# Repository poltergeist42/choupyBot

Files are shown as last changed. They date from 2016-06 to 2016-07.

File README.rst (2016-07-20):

=========
choupyBot
=========

   :Autheur:          `Poltergeist42 <https://github.com/poltergeist42>`_
   :Organistation:    `VoLAB <https://github.com/volab>`_
   :Projet:           `choupyBot <https://github.com/volab/choupyBot>`_
   :Licence:          CC BY-NC-SA 4.0
   :Liens:            https://creativecommons.org/licenses/by-nc-sa/4.0/ 

------------------------------------------------------------------------------------------

Description
===========

ChoupyBot est un petit "robot" animé par un Raspberry pi et motoriser par 2 moteurs
pas à pas (PAP) et un capteur ultrason.

L'objectif de ce projet et de réaliser une petite plateforme ludique qui pourra être
programmée / commandée à distance par un enfant. Ce robot évoluera dans un quadrillage
de 15x15.

**N.B :** la dimension des cases sera déterminée ultérieurement en fonction
de la taille du robot.

Voir le doc de conception pour plus de détail :
https://github.com/volab/choupyBot/blob/master/_1_userDoc/choupyBot_doc.rst

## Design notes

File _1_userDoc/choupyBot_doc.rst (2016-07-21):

=========
choupyBot
=========

   :Autheur:                    `Poltergeist42 <https://github.com/poltergeist42>`_
   :Organistation:              `VoLAB <https://github.com/volab>`_
   :Projet:                     `choupyBot <https://github.com/volab/choupyBot>`_
   :Licence:                    CC BY-NC-SA 4.0
   :Liens:                      https://creativecommons.org/licenses/by-nc-sa/4.0/ 

------------------------------------------------------------------------------------------

    :Version:                   20160721

------------------------------------------------------------------------------------------

Outils de conception
=======================

    :Langage de programmation:  Python (v3.4)
    :modelisation 3D:           Fusion 360
    :Circuit imprime:           Kicad (v4.0.2)

------------------------------------------------------------------------------------------

Description
===========

ChoupyBot est un petit "robot" animé par un Raspberry pi et motoriser par 2 moteurs
pas à pas (PAP) et un capteur ultrason.

L'objectif de ce projet et de réaliser une petite plateforme ludique qui pourra être
programmée / commandée à distance par un enfant. Ce robot évoluera dans un quadrillage
de 15x15.

**N.B :** la dimension des cases sera déterminée ultérieurement en fonction
de la taille du robot.

------------------------------------------------------------------------------------------

Descriptif détaillé
===================

    #. Liste des équipements
        * Un capteur ultrason
            Il vat permettre la détection des obstacles. Un potentiomètre sera associé
            à ce capteur pour permettre de modifier la distance de sécurité avant
            Évitement des obstacles.
            
            **N.B :** Le RPi n'étant pas équiper d'une entrée analogique et ne voulant
            ajouter un CAN, le potentiomètre ne sera pas intégré pour l'instant.
            
        * Un bouton "Start"
            Lorsque la programmation du robot par l'utilisateur sera terminé,
            le robot attendra que le bouton "Start" soit enfoncé avant de commencer.
            Des LED peuvent être placés à coté pour indiquer si on est en mode Action
            ou Programmation
            
            **N.B** : Si le bouton n'est pas physique mais fait partie de l'interface,
            il ne sera pas nécessaire d'ajouter les LED.
            
    #. Les modes disponibles sont
    
        * **Boxxle** : Le robot doit manipuler une boite sur un damier a fin de la
          ranger sur un emplacement défini en évitant les obstacles. Les
          Instructions seront données par un opérateur depuis un terminal externe.
          
        * **Parcours** : Le robot doit suivre un parcours (ou un labyrinthe).
          Lorsque le robot aura suivi le parcours ou résolue le labyrinthe, le
          robot pourra refaire le trajet de façon optimisé.
          
        * **Aventure** : le robot évolue librement au sol et réagi en fonction des
          obstacles qu'il rencontre.
          
          **N.B** : Le Robot n'ayant qu'un seul capteur, ce dernier ne réagira
          pas beaucoup.
            
    #. Besoin et fonctionnalités pour la "programmation" coté publique
        * Création d'un programme et d'un interface pour tablettes Android et / ou PC
            - 4 boutons de base : Avance, Recul, Gauche, Droite
            - 1 menu déroulant permettant de choisir le mode disponible : Boxxle, Parcours,
              Aventure.
            - 1 paire de bouton radio Start / Stop
            
        * Arrêt du système
            - L'interface doit contenir un onglet ; une page ; ou un bouton permettant
              d'éteindre le RPi. Une foie le système arréter, un message doit nous
              informer que l'appareil peut être mis hors tension.

------------------------------------------------------------------------------------------

Références matériels
====================

    :reference du moteur Pas a Pas:         28BJY-48
    :reference du driver pour le PAP:       UNL2003
    :reference du capteur ultrason:         HC-SR04
    :reference du Raspberry Pi:             Raspberry Pi2
    :reference Battery:                     Lipo Battery 7.4V
    :reference abaisseur de tension:        UBEC 5v 3a
    :reference electronique:
        +------------------------------------------------------------------------------+
        |                           Carte éléctronique                                 |
        +--------------------------+-----+---------------------------------------------+
        |          Référence       | QTE |                 Descriptif                  |
        +==========================+=====+=============================================+
        | Resistor 20K             |  1  | pond diviseur pour abesser la tension en    |
        +--------------------------+-----+ sortie de la broche 'echo' (+5v) jusqu'à la |
        | Resistor 10k             |  1  | tension d'entrée des GPIO du RPi            |
        +--------------------------+-----+---------------------------------------------+
        | Resistor 330R            |  1  | Control de reception, par 'echo', du son    |
        +--------------------------+-----+ émit par 'trig'. Cette ensemble est         |
        | Red LED 5mm              |  1  | facultatif                                  |
        +--------------------------+-----+---------------------------------------------+
        | Pin_Header_Straight_1x02 |  2  | P1, entrée Ubec. P10 N.U, en cas de besoin  |
        +--------------------------+-----+---------------------------------------------+
        | Pin_Header_Straight_1x03 |  1  | Broches I2c du Pi, en cas de besoin         |
        +--------------------------+-----+---------------------------------------------+
        | Pin_Header_Straight_2x20 |  1  | Pour relier le PCB au Pi                    |
        +--------------------------+-----+---------------------------------------------+
        | XH_connector_4pins_Vert  |  3  | Pour le sonar et les 2 drivers de PAP       |
        +--------------------------+-----+---------------------------------------------+
        | XH_connector_2pins_Vert  |  4  | Pour alimenter les diférents elements       |
        +--------------------------+-----+---------------------------------------------+
        | 40 Pin Flat grey Ribbon  |  1  | Nape permettant de relier le RPi à la carte |
        | Cable                    |     | du robot                                    |
        +--------------------------+-----+---------------------------------------------+
        | 40 Pin IDC FC Female     |     | Connecteur à placer sur chaque extremité    |
        | Header Cable Socket      |  2  | de la nape une fois coupée aux bonnes       |
        | Connector FC-40          |     | dimensions                                  |
        +--------------------------+-----+---------------------------------------------+
        
        +------------------------------------------------------------------------------+
        |                           Autres Composant                                   |
        +--------------------------+-----+---------------------------------------------+
        |          Référence       | QTE |                 Descriptif                  |
        +==========================+=====+=============================================+
        | Mini Digital Voltmeter   |  1  | Permet de mesurer la tension de la battery  |
        +--------------------------+-----+---------------------------------------------+
        | spdt toggle switch 2     |  1  | Switch Permettant la mise sous tension et   |
        | position                 |     | la mise hors tension                        |
        +--------------------------+-----+---------------------------------------------+
        
    :ref fournisseur:
        * `Resistor <http://www.aliexpress.com/item/1Pack-300Pcs-10-1M-Ohm-1-4w-Resistance-1-Metal-Film-Resistor-Resistance-Assortment-Kit-Set/32505894332.html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,searchweb201602_3_10057_10056_10055_10037_10049_10033_10059_10032_10058_10017_405_404_407_10040,searchweb201603_1&btsid=8e5d318c-a269-4c5b-a395-16bc8a31fc73>`_
        
        * `Red LED 5mm <http://www.aliexpress.com/item/Free-shipping-100pcs-Red-LED-5MM-Red-light-emitting-diode-Red-turn-Red/32628839823.html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,searchweb201602_3_10057_10056_10055_10037_10049_10033_10059_10032_10058_10017_405_404_407_10040,searchweb201603_1&btsid=47854a59-62f5-488d-87f2-74b3ebb1b718>`_

        * `Pin_Header_Straight(SIL) <http://www.aliexpress.com/item/20pcs-lot-Connector-2-54mm-40-Pin-Male-Single-Row-silver-Pin-Header-Strip-Free-Shipping/606254600.html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,searchweb201602_3_10057_10056_10055_10037_10049_10033_10059_10032_10058_10017_405_404_407_10040,searchweb201603_1&btsid=45858581-d831-43e6-adae-868ebc290c68>`_

        * `Pin_Header_Straight (DIL) <http://www.aliexpress.com/item/5PCS-LOT-2-54mm-2-x-40-Pin-Male-Double-Row-Pin-Header-Strip-pin-header/32639552444.html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,searchweb201602_3_10057_10056_10055_10037_10049_10033_10059_10032_10058_10017_405_404_407_10040,searchweb201603_1&btsid=45858581-d831-43e6-adae-868ebc290c68>`_

        * `XH_connector <http://www.aliexpress.com/item/40-sets-Kit-in-box-2p-3p-4p-5-pin-2-54mm-Pitch-Terminal-Housing-Pin/32682649292.html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>`_
 
        * `40 Pin Flat grey Ribbon Cable <http://www.aliexpress.com/item/1meter-free-shipping-40-Pin-1-27mm-Spacing-2-54mm-Pitch-Extension-Flat-grey-Ribbon-Cable/32695430026.html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>`_
        
        * `40 Pin IDC FC Female Header Cable Socket Connector FC-40 <http://www.aliexpress.com/item/50-Pcs-2-54mm-2x20-Pin-40-Pin-IDC-FC-Female-Header-Cable-Socket-Connector-FC/32425419419.html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,searchweb201602_3_10057_10056_10055_10037_10049_10033_10059_10032_10058_10017_405_404_407_10040,searchweb201603_1&btsid=aadd4877-4555-4aa3-bfb5-1c5a960b74ee>`_
        
        * `Step motor + Drivers <http://www.aliexpress.com/item/5V-4-Phase-Stepper-Step-Motor-Driver-Board-ULN2003-With-Drive-Test-Module-Machinery-Board-Tools/32532201168.html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,searchweb201602_3_10057_10056_10055_10037_10049_10033_10059_10032_10058_10017_405_404_407_10040,searchweb201603_1&btsid=5e1b0c4c-c554-49cf-8065-2a162d1b7fc5>`_
        
        * `HC-SR04 Ultrasonic <http://www.aliexpress.com/item/5pcs-HC-SR04-Ultrasonic-Module-Distance-Measuring-Transducer-Sensor-Detector-Ranging-Module-DC-5V/1787674353.html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,searchweb201602_3_10057_10056_10055_10037_10049_10033_10059_10032_10058_10017_405_404_407_10040,searchweb201603_1&btsid=fbf652a2-1388-4059-8230-f07c7a479e81>`_

        * `Raspberry Pi 3 (le 2 est épuisé) <http://www.rs-particuliers.com/WebCatalog/Raspberry_Pi_Model_3_B_SBC-8968660.aspx>`_
        
        * `Lipo Battery 7.4V <http://www.aliexpress.com/item/New-Lion-Power-Lipo-Battery-7-4V-2S-900Mah-25C-High-Power-For-RC-Helicopter-Quadcopter/32490119056.html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,searchweb201602_3_10057_10056_10055_10037_10049_10033_10059_10032_10058_10017_405_404_407_10040,searchweb201603_1&btsid=5df62305-c0ef-4954-b372-49875b600234>`_
        
        * `UBEC <http://www.aliexpress.com/item/DC-Converter-Module-3A-5V-Mini-UBEC-For-RC-Plane-Quadcopter-UBEC-For-FPV-Image-Transmission/32672871968.html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,searchweb201602_3_10057_10056_10055_10037_10049_10033_10059_10032_10058_10017_405_404_407_10040,searchweb201603_1&btsid=782431b5-bf7c-4989-af00-d58d274b1460>`_
        
        * `Mini Digital Voltmeter <http://www.banggood.com/0_28-Inch-2_5V-30V-Mini-Digital-Voltmeter-p-974258.html>`_
        
        * `spdt toggle switch <http://www.aliexpress.com/item/2-Pcs-AC-125V-6A-Amps-ON-ON-2-Position-3-Pins-SPDT-Mini-Toggle-Switch/32616445190.html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,searchweb201602_3_10057_10056_10055_10037_10049_10033_10059_10032_10058_10017_405_404_407_10040,searchweb201603_1&btsid=3ba9a450-a00f-4e04-ab23-c6719cd05a1d>`_

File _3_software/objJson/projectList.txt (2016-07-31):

C:/mntJeanCloud/Perso/LAB/Pierre/raspberryPi/projet/choupyBot/_3_software

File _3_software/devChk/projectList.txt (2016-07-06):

C:/mntJeanCloud/Perso/LAB/Pierre/raspberryPi/projet/scanner3d/_3_software
C:/mntJeanCloud/Perso/LAB/Pierre/raspberryPi/projet/choupyBot/_3_software

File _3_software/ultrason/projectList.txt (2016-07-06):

C:/mntJeanCloud/Perso/LAB/Pierre/raspberryPi/projet/choupyBot/_3_software

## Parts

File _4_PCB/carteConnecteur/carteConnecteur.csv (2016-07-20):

Id | Référence | Boîtier | Quantité | Désignation | Fournisseur et réf.
1 | D1 | LED-5MM | 1 | LED
2 | P6 | Pin_Header_Straight_2x20 | 1 | RPi_Conn
3 | P10 | Pin_Header_Straight_1x02 | 1 | N.U
4 | R1 | Resistor_Vertical_RM5mm | 1 | 20k
5 | R2 | Resistor_Vertical_RM5mm | 1 | 10k
6 | R3 | Resistor_Vertical_RM5mm | 1 | 330R
7 | P11 | Pin_Header_Straight_1x03 | 1 | I2c
8 | REF**,REF** | MountingHole_3.7mm_Pad | 2 | MountingHole_3.7mm_Pad
9 | P1 | Pin_Header_Straight_1x02 | 1 | +5 (ubec)
10 | P2 | XH_connector_4pins_Vert | 1 | PAP_D
11 | P3 | XH_connector_2pins_Vert | 1 | +5 (pap_G)
12 | P4 | XH_connector_2pins_Vert | 1 | +5 (pap_D)
13 | P5 | XH_connector_4pins_Vert | 1 | PAP_G
14 | P7 | XH_connector_2pins_Vert | 1 | +5 (sonar)
15 | P8 | XH_connector_2pins_Vert | 1 | +5 (RPi)
16 | P9 | XH_connector_4pins_Vert | 1 | HC-SR04

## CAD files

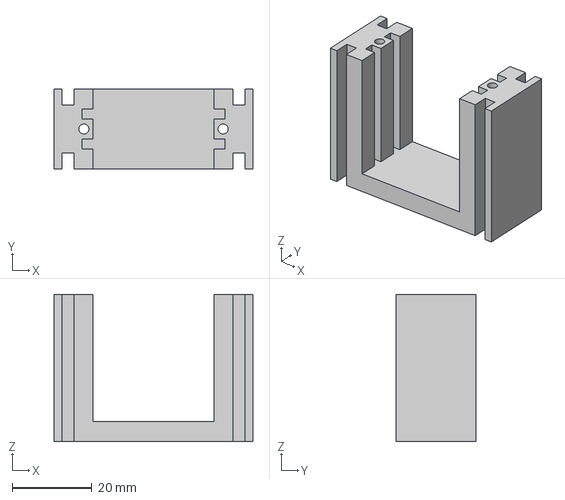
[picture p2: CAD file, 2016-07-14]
_2_modelization/fusion 360/supportElectronique v9.iges
50.0 x 20.0 x 37.0 mm

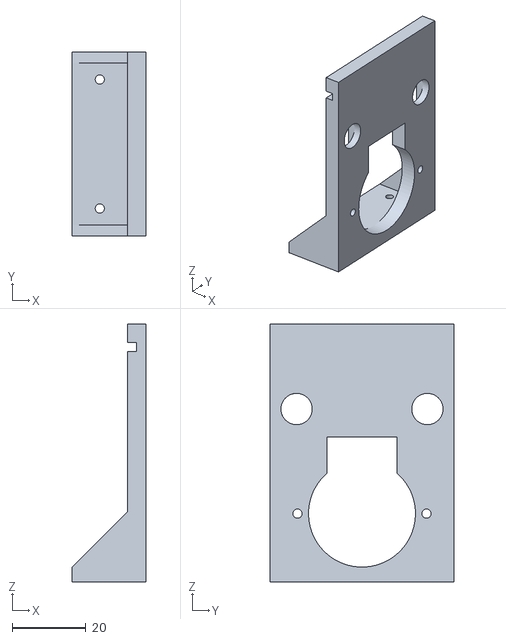
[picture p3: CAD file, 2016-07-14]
_2_modelization/stl/equerreMoteur.stl
20.0 x 50.0 x 70.0

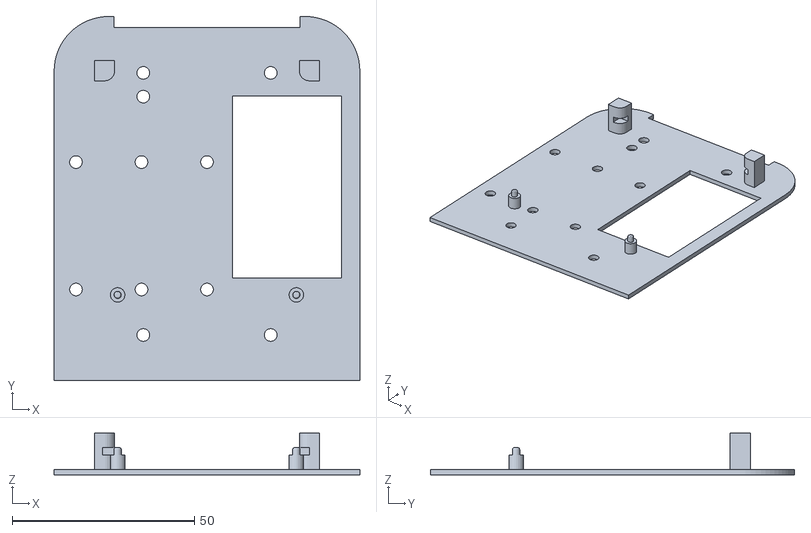
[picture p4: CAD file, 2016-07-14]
_2_modelization/stl/supportPi v16.stl
84.0 x 100.0 x 11.5

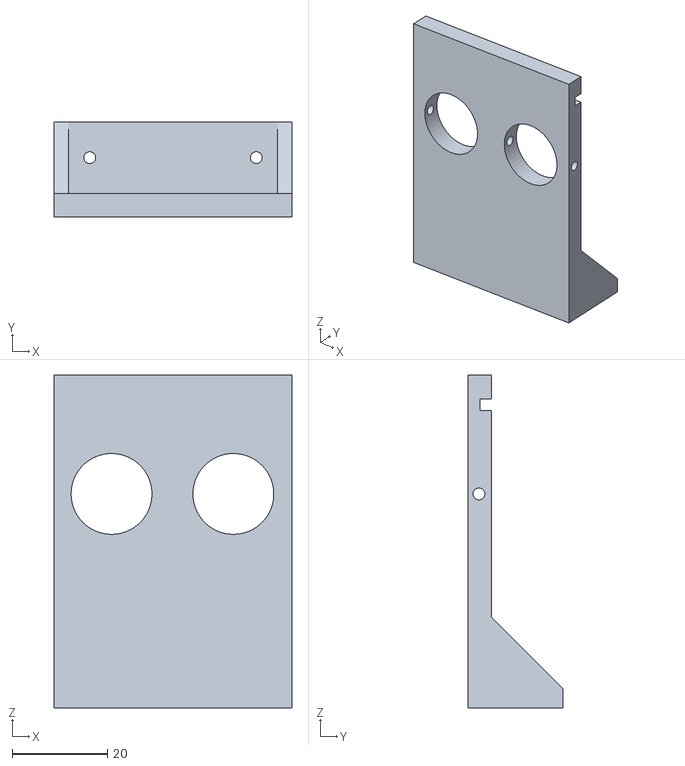
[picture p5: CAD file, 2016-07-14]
_2_modelization/stl/equerreSonar.stl
50.0 x 20.0 x 70.0

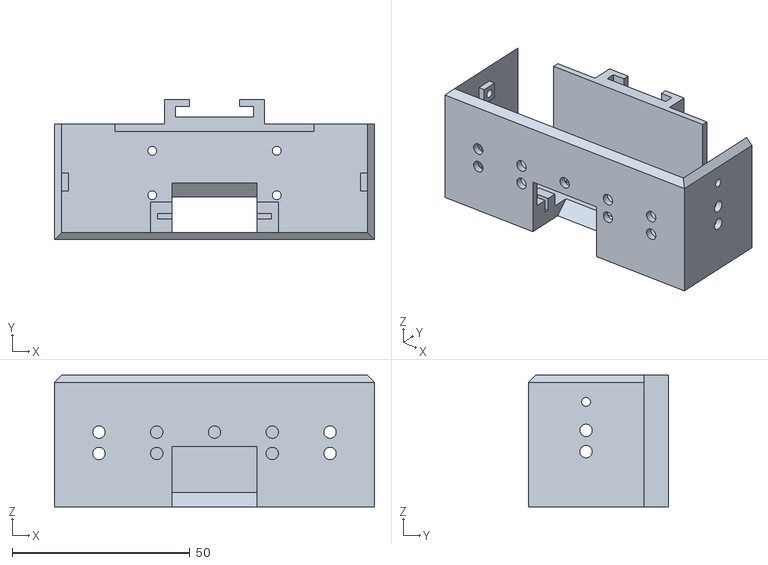
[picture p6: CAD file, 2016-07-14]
_2_modelization/stl/packBattery v23.stl
90.0 x 39.5 x 37.0

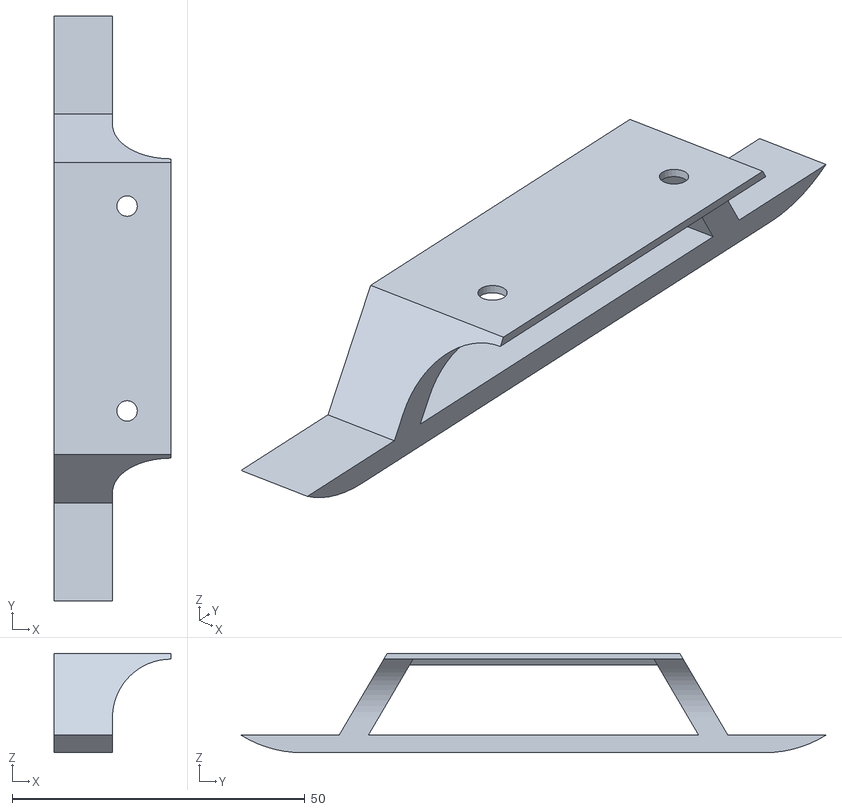
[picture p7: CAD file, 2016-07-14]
_2_modelization/stl/patin v8.stl
20.0 x 100.0 x 17.0

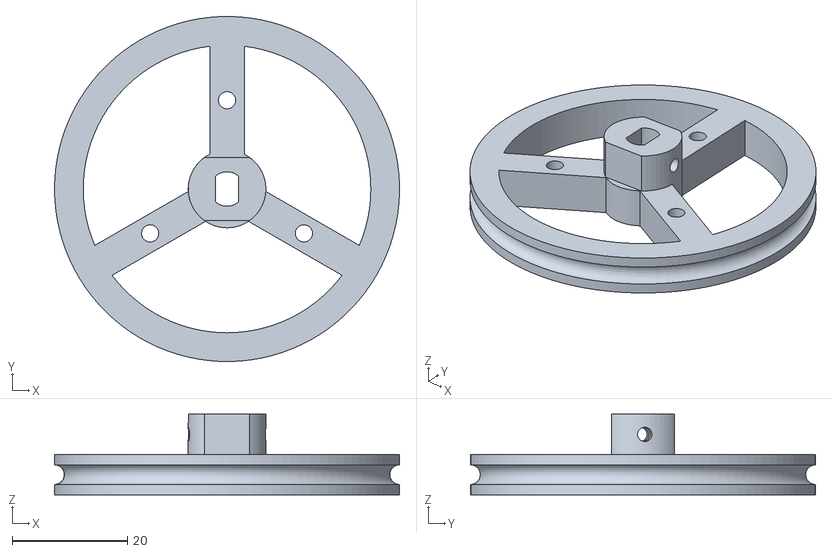
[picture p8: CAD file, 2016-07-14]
_2_modelization/stl/roue v8.stl
60.0 x 60.0 x 14.0

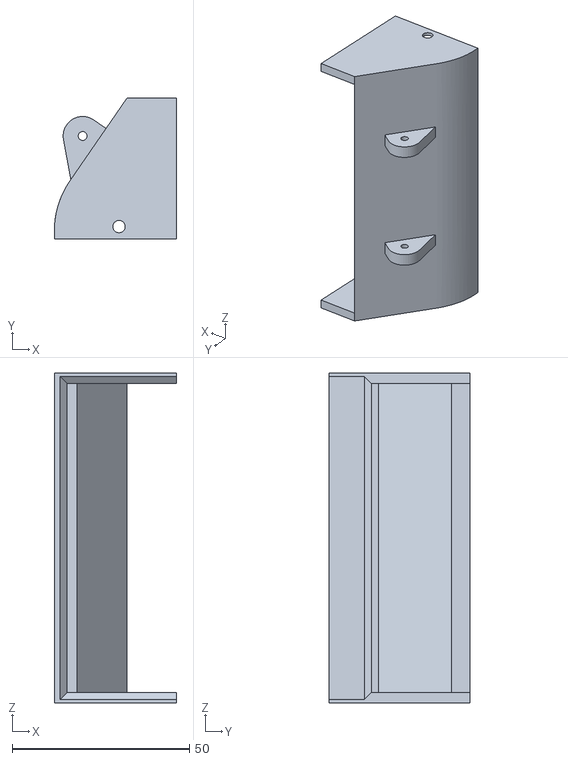
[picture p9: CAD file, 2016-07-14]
_2_modelization/stl/capotDeCoffre v16.stl
34.5 x 39.8 x 93.0

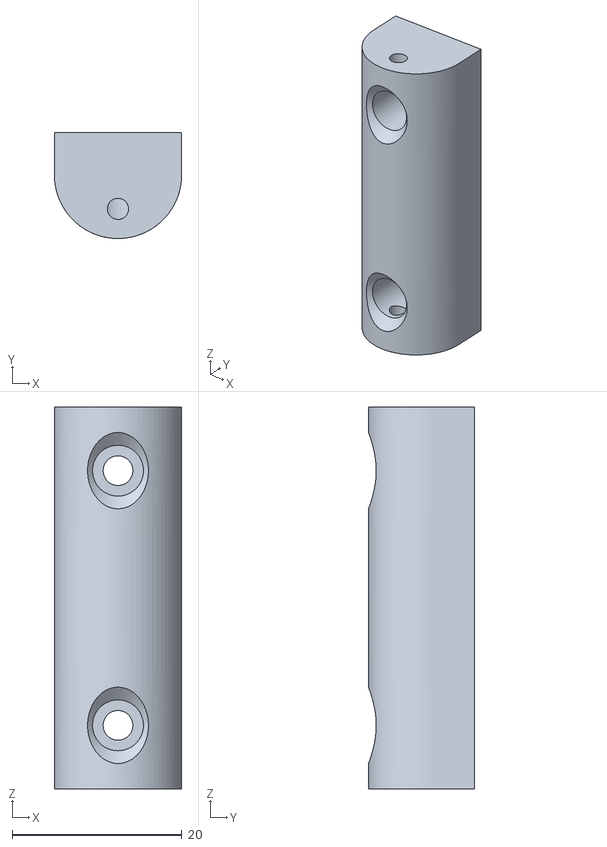
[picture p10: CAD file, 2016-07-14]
_2_modelization/stl/support.stl
15.0 x 12.5 x 45.0

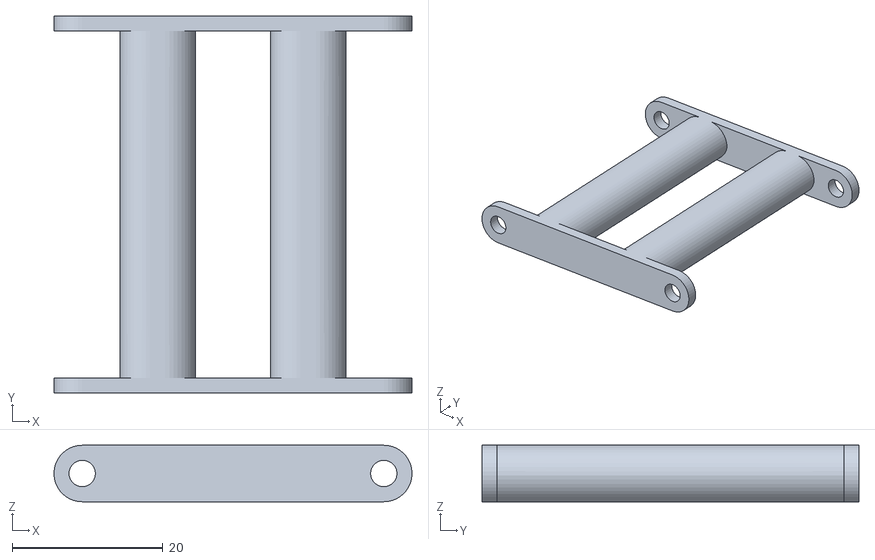
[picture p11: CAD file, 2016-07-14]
_2_modelization/stl/fixationCapotSpoiler v4.stl
47.5 x 50.0 x 7.50

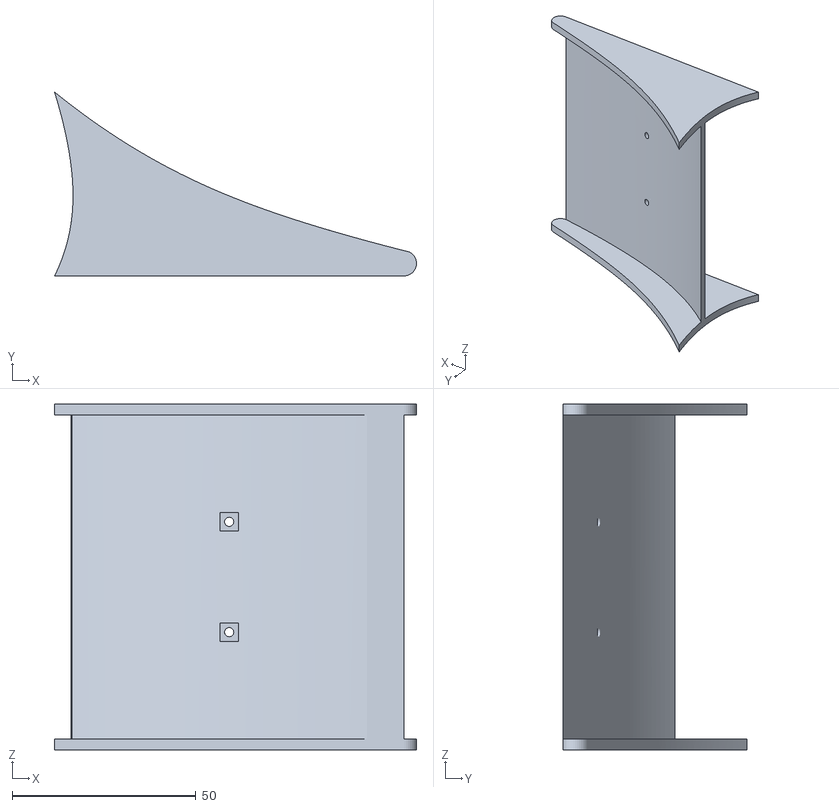
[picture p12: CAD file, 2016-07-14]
_2_modelization/stl/spoiler.stl
98.4 x 50.0 x 94.0

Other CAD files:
_2_modelization/stl/supportElectronique v9.stl
_2_modelization/fusion 360/capotDeCoffre v16.f3d
_2_modelization/fusion 360/equerreMoteur.f3d
_2_modelization/fusion 360/equerreSonar.f3d
_2_modelization/fusion 360/fixationCapotSpoiler v4.f3d
_2_modelization/fusion 360/packBattery v23.f3d
_2_modelization/fusion 360/patin v8.f3d
_2_modelization/fusion 360/roue v8.f3d
_2_modelization/fusion 360/spoiler v9.f3d
_2_modelization/fusion 360/supportPi v16.f3d

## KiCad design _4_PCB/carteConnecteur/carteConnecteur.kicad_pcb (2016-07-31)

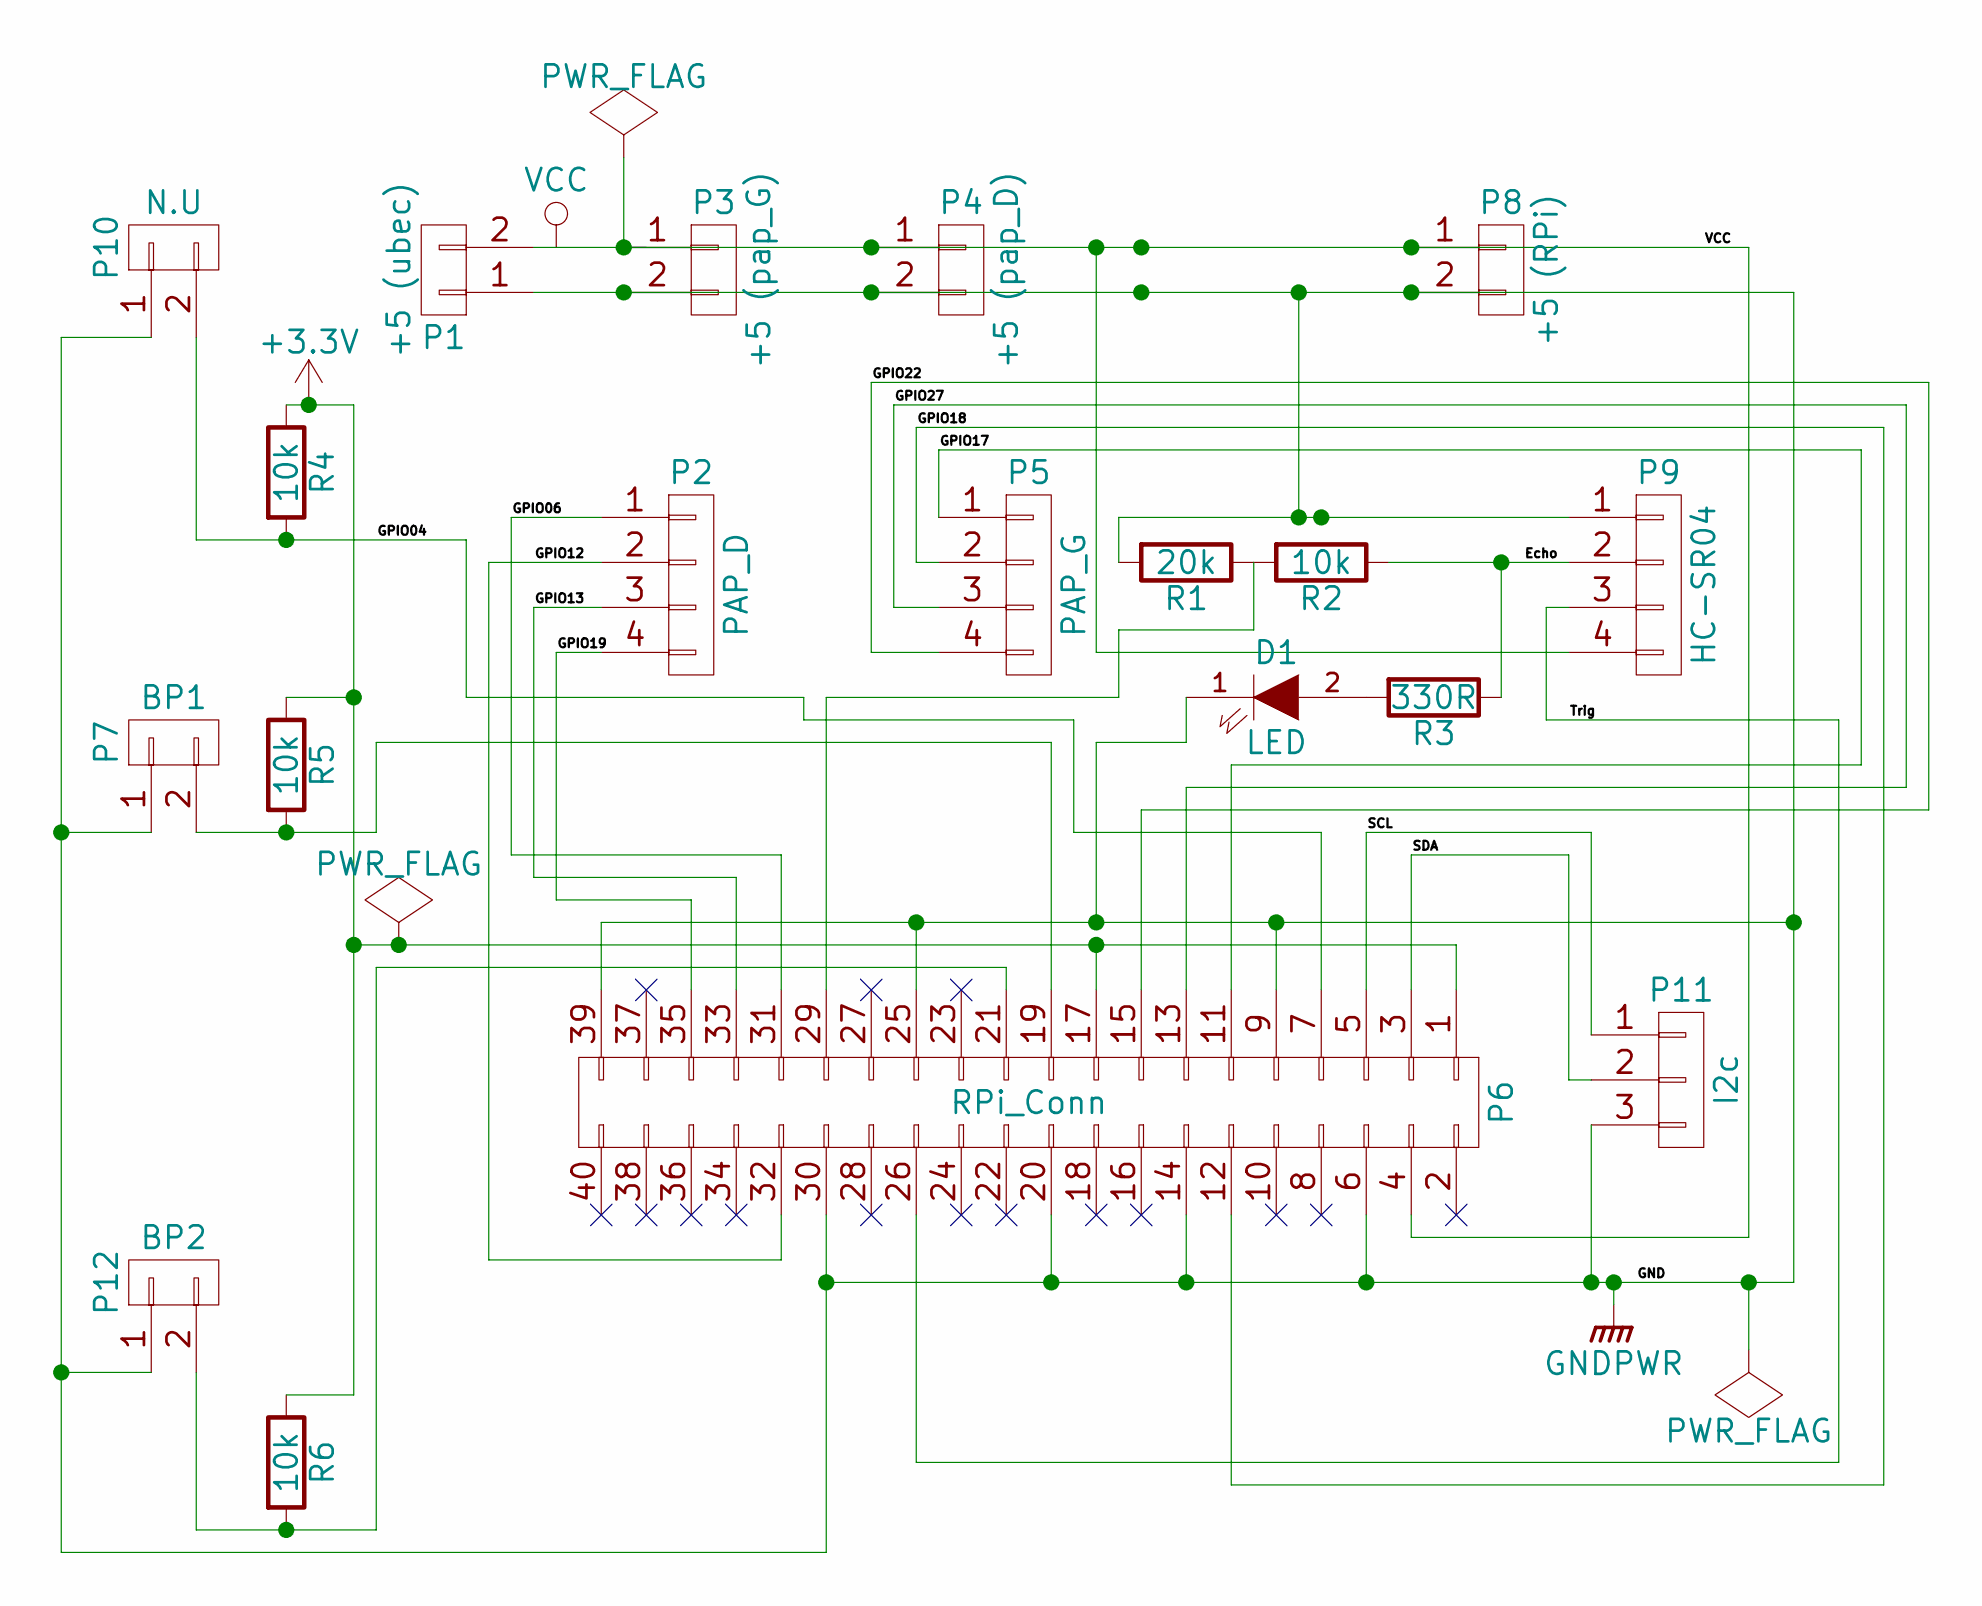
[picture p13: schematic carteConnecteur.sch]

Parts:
D1: LED; LED-5MM
P1: +5 (ubec); Pin_Header_Straight_1x02
P2: PAP_D; XH_connector_4pins_Vert
P3: +5 (pap_G); XH_connector_2pins_Vert
P4: +5 (pap_D); XH_connector_2pins_Vert
P5: PAP_G; XH_connector_4pins_Vert
P6: RPi_Conn; Pin_Header_Straight_2x20
P7: BP1; Pin_Header_Straight_1x02
P8: +5 (RPi); XH_connector_2pins_Vert
P9: HC-SR04; XH_connector_4pins_Vert
P10: N.U; Pin_Header_Straight_1x02
P11: I2c; Pin_Header_Straight_1x03
P12: BP2; Pin_Header_Straight_1x02
R1: 20k; Resistor_Vertical_2-54
R2, R4, R5, R6: 10k; Resistor_Vertical_2-54
R3: 330R; Resistor_Vertical_2-54

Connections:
+3V3: P6.1, P6.17, R4.1, R5.1, R6.1
/Echo: P9.2, R2.1, R3.1
/GPIO04: P6.7, P10.2, R4.2
/GPIO06: P2.1, P6.31
/GPIO12: P2.2, P6.32
/GPIO13: P2.3, P6.33
/GPIO17: P5.1, P6.11
/GPIO18: P5.2, P6.12
/GPIO19: P2.4, P6.35
/GPIO22: P5.4, P6.15
/GPIO27: P5.3, P6.13
/SCL: P6.5, P11.1
/SDA: P6.3, P11.2
/Trig: P6.26, P9.3
GNDPWR: D1.1 (K), P1.1, P3.2, P4.2, P6.6, P6.9, P6.14, P6.20, P6.25, P6.30, P6.39, P7.1, P8.2, P9.1, P10.1, P11.3, P12.1, R1.2
unnamed: D1.2 (A), R3.2
unnamed: P6.19, P7.2, R5.2
unnamed: P6.29, R1.1, R2.2
unnamed: P6.21, P12.2, R6.2
VCC: P1.2, P3.1, P4.1, P6.4, P8.1, P9.4

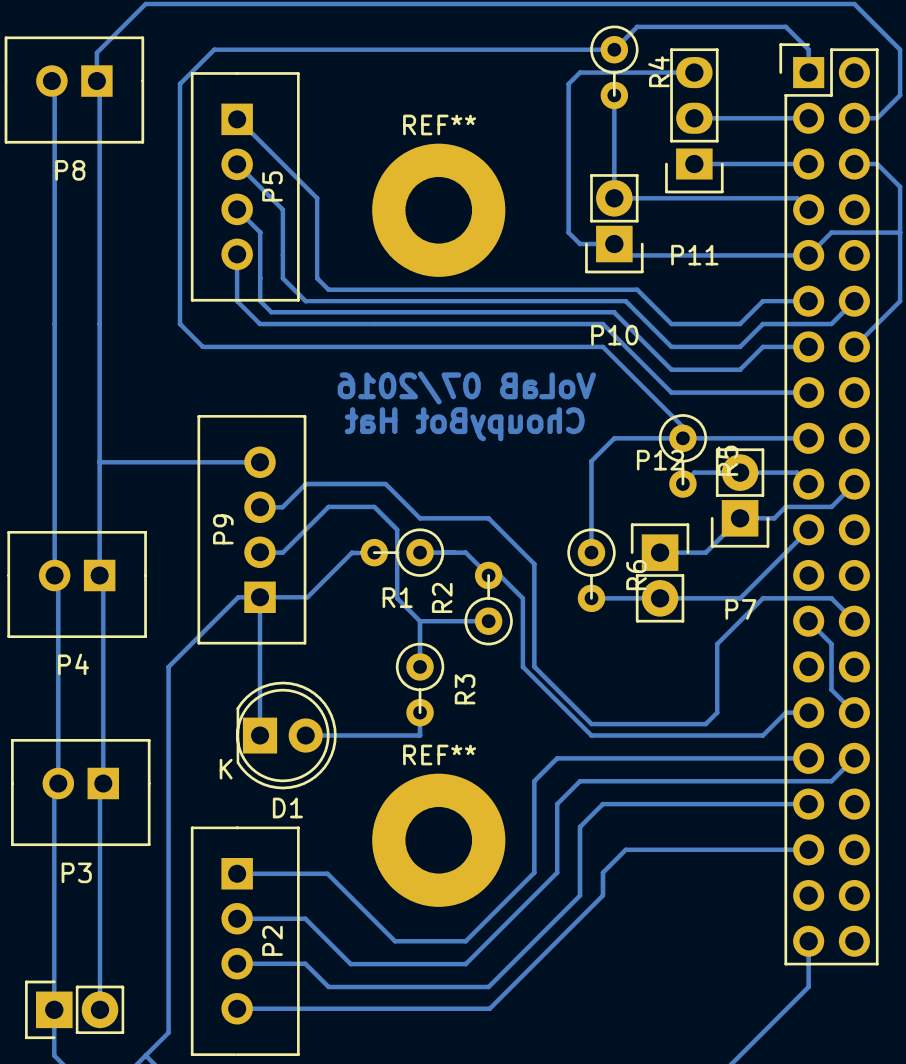
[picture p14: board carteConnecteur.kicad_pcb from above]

Board: 2 copper layers, 19 parts (0 on the bottom side), 20 nets.

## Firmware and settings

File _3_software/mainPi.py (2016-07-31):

#!/usr/bin/env python
# -*- coding: utf-8 -*-

"""

=========
choupyBot
=========

   :Nom du fichier:     choupyBot.py
   :Autheur:            `Poltergeist42 <https://github.com/poltergeist42>`_
   :Version:            20160731

####

   :Licence:            CC-BY-NC-SA
   :Liens:              https://creativecommons.org/licenses/by-nc-sa/4.0/

####

    :dev language:      Python 3.4
    
####

lexique
=======

   :**v_**:                 variable
   :**l_**:                 list
   :**t_**:                 tuple
   :**d_**:                 dictionnaire
   :**f_**:                 fonction
   :**C_**:                 Class
   :**i_**:                 Instance
   :**m_**:                 Module
"""
try :
    from moteurPap.moteurPap import C_MoteurPap
except ImportError :
    print( "module 'moteurPap' non charge") 

try :
    from ultrason.ultrason import C_ultrasonSensor
except ImportError :
    print( "module 'ultrason' non charge")
    
try :
    from devChk.devChk import C_DebugMsg
except ImportError :
    print( "module 'devChk' non charge")
    
try :
    from objJson.objJson import C_ObjJson
except ImportError :
    print( "module 'objJson' non charge")

class C_choupyBot(object) :
    def __init__(self, ):
        """ variables globales """
        
        ## Creation de l'instance de C_DebugMsg
        self.i_dbg = C_DebugMsg()
        
        ## Variables globales
        self.v_case = 15
        self.v_mode = ""
        
        
        
    def __del__(self) :
        """ Destructor
        
            Permet de fremer proprement l'instance en cours.
            il faut utilise :
            ::
            
                del [nom_de_l'_instance]
                
            N.B : cette methode est appelee automatiquement par le ramasse miette si
            l'instance n'est plus solicitee.
        """
        v_className = self.__class__.__name__
        print("\n\t\tL'instance de la class {} est terminee".format(c_className))

        
    def f_setMode(self, v_mode = "boxxle") :
        """ identification / modification du mode de fonctionnement du robot
        
            Le Robot peut être parametrer pour fonctionner selon plusieur mode.
            
            **Les modes disponibles sont :**
            
                * Boxxle (mode par defaut)
                * Parcours
                * Aventure
        """
        if v_mode == "boxxle" or v_mode == "parcours" or v_mode == "aventure"
            self.v_mode = v_mode
        else : self.v_mode = "boxxle"
        
    def f_papInit(self):
        """ initialisation des 2 moteur pas a pas (pap)
        
            +------------+-------------------------+
            | BCM (GPIO) | Serigraphie sur UNL2003 |
            +============+=========================+
            |   v_gpioA  |           N1            |
            +------------+-------------------------+
            |   v_gpioB  |           N2            |
            +------------+-------------------------+
            |   v_gpioC  |           N3            |
            +------------+-------------------------+
            |   v_gpioD  |           N4            |
            +------------+-------------------------+
           
            le papGauche est intialiser sur les GPIO par defaut soit ::
           
                v_gpioA = GPIO17
                v_gpioB = GPIO18
                v_gpioC = GPIO27
                v_gpioD = GPIO22
           
            et tourne dans le sens anti-horriare.
            le papDroit est initialiser sur un autre jeux de GPIO ::
           
                v_gpioA = GPIO06
                v_gpioB = GPIO12
                v_gpioC = GPIO13
                v_gpioD = GPIO19
                
            et tourne dans le sens horriare. La valeur de v_rayonInit correspond
            au rayon des roues du robot. Les deux pap tournes en sens inverse l'un de 
            l'aure, pour que le robot puisse aller tout droit.
        """
       
        ## papGauche
        self.i_papGauche = C_MoteurPap(v_rotationInit = "antihorraire", v_rayonInit = 3)
        self.i_papGauche.f_gpioInit(v_gpioA=06, v_gpioB=12, v_gpioC=13, v_gpioD=19)
        
        ## papDroit
        self.i_PapDroit  = C_MoteurPap(v_rayonInit = 3)
        self.i_PapDroit.f_gpioInit()

                                        
    def f_sonarInit(self) :
        """ Initialisation du capteur ultrason

        La broche du trig et configuer sur GPIO 7 par défaut.
        La broche echo ayant le GPIO 12 par defaut, elle a ete reconfiguree
        sur GPIO 5
        """
        
        i_ultrason = C_ultrasonSensor()
        i_ultrason.f_ultraInit(v_gpioEcho = 5)
    
    def f_avance(self) :
        """ avance tout droit """
        
    def f_recul(self) :
        """ reculler tout droit """
        
    def f_gauche(self) :
        """ tourner a gauche """
        
    def f_droite(self) :
        """ Tourner a droite """

def main() :
    """ Fonction principal """
    i_choupy = C_choupyBot()
    i_choupy.f_papInit()
    i_choupy.f_sonarInit()

    
    
if __name__ == '__main__':
    main()

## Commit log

2016-06-08 ajout de "VoLAB.rst" a la racine de l'arbo
2016-06-11 Creation de la bibliotheque 'ultrason'
2016-06-11 creation de 'choupyBot_doc.rst'
2016-06-12 preparation des fonctions de deplacement dans 'mainPi'
2016-06-12 ajout de la fonction "f_sensDeRotation" modified: 03_software/moteurPap.py
2016-06-12 factorisation de la sequence de mouvement des PAP
2016-06-12 Ajout des fonctions de conversion des cm en deg et en step
2016-06-12 ajout du destructor '__del__', ajout d'une fonction main pour les test
2016-06-12 ajout de la methode '__del__' et d'une fonction 'main' dans ultrason.py
2016-07-04 modification des noms de l'arborescence
2016-07-06 ajout des lib 'devChk', 'moteurPap' et 'ultrason'
2016-07-06 ajout de la methode 'f_sonarInit'
2016-07-11 ajout de la fonction 'f_setMode' dans 'mainPi'
2016-07-14 modelisation du robot sous fusion 360 + mise a dispo des sources et des STL
    [capotDeCoffre v16.f3d, capotDeCoffre v16.stl, equerreMoteur.f3d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]
2016-07-15 modif mineur dans le doc de conception
2016-07-20 conception du PCB
    [carteConnecteur.csv, carteConnecteur.kicad_pcb, carteConnecteur.sch]
2016-07-20 ajout de la liste des composant dans le doc de conception
2016-07-20 complement de la liste de materiel
2016-07-21 complement du doc de conception : 'choupyBot_doc.rst'
2016-07-31 ajout de 3 connecteur + pull-up sur le PCB + mise à jour des libs dans 'software'
    [carteConnecteur.kicad_pcb, carteConnecteur.sch]
